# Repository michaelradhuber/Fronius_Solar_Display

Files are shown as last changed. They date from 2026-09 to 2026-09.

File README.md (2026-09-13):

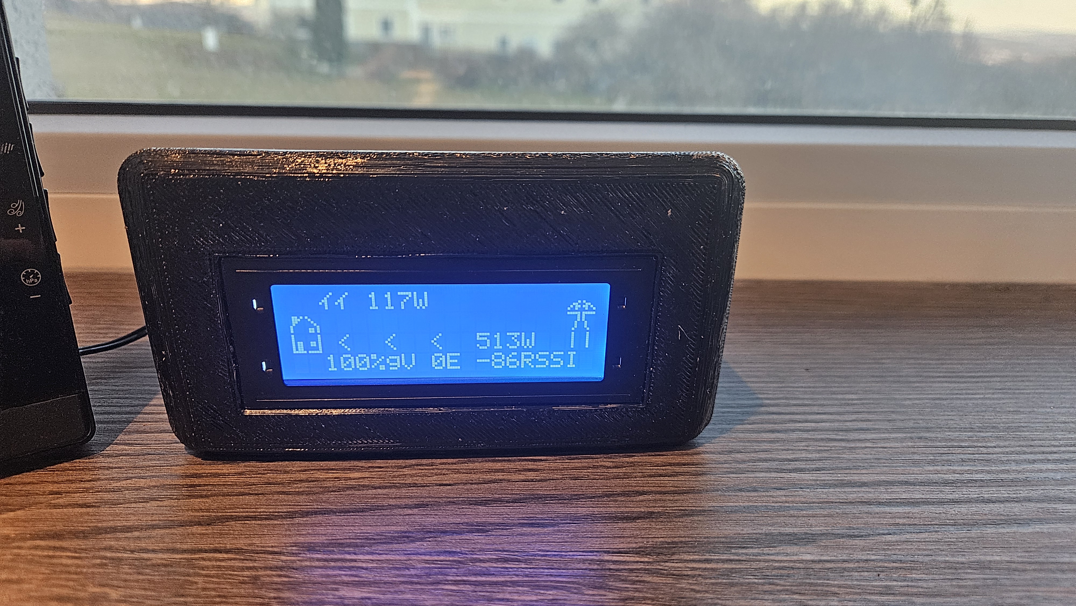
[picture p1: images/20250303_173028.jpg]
20x4 LCD solar display


# Fronius Solar Display

An ESP32 (Arduino) based solar power display that reads photovoltaic production, grid
import/export and home consumption from a Fronius inverter's **Solar API v1** and shows them
on a cheap 20×4 character LCD — no I²C backpack, no app, no website.

Put it somewhere you actually walk past: kitchen, hallway, living room. Its whole purpose is
a glance that tells you whether now is a good moment to run the dishwasher.

> **This is v2.** The v1 code is preserved on the [`v1` branch](../../tree/v1), along with
> its Fritzing sketch. The application logic is the same; v2 rewrites the hardware layer,
> fixes a set of latent memory bugs, adds OTA and makes the WiFi link actually survive a
> marginal signal. [ARCHITECTURE.md](ARCHITECTURE.md) documents all of it.

## System requirements

- A Fronius inverter with **Solar API v1** (Symo, Galvo, Gen24, Tauro …).
- A **Fronius Smart Meter** installed alongside your main electricity meter and connected to
  the inverter — without it there are no grid figures. Supplemental inverters not directly
  connected also work, provided they are registered via a Smart Meter.
- An IPv4 network, preferably a /24 (`255.255.255.0`) subnet.

## Features

- PV production, grid import/export and home consumption on a 20×4 LCD.
- Maximum grid-voltage deviation (`gV`). European grids run 230 V with a 10% (23 V) limit.
- WiFi signal strength (`RSSI`) and inverter connection errors (`E`), errors self-clearing
  after five minutes.
- Configured over WiFi through a captive portal ([WiFiManager](https://github.com/tzapu/WiFiManager)
  by @tzapu) — no credentials in the source.
- Remembers the inverter's IP **and MAC**, and re-finds it by MAC when DHCP moves it.
- **OTA updates** over WiFi once the first USB flash is done.
- Survives a weak link: radio tuning (power-save off, HT20, 802.11b retained), a blocking
  boot-connect retry loop, and active reconnect supervision rather than trusting the stack.

## Hardware

| | |
|---|---|
| **Board** | ESP32-WROOM-32 DevKit (4 MB flash) — v2 was developed on a uPesy board |
| **Display** | HD44780-compatible 20×4 character LCD, 4-bit parallel, run at **5 V** |
| **Contrast** | B10K potentiometer |
| **Power** | **An external 5 V supply — see below** |
| **Input** | The board's on-board BOOT button |

### Wiring

| LCD pin | Signal | ESP32 |
|---|---|---|
| 4 | RS | GPIO 13 |
| 6 | E | GPIO 33 |
| 11 | D4 | GPIO 14 |
| 12 | D5 | GPIO 27 |
| 13 | D6 | GPIO 26 |
| 14 | D7 | GPIO 25 |
| 1, 5, 16 | VSS, **RW**, backlight cathode | GND |
| 2, 15 | VDD, backlight anode | 5V |
| 3 | V0 | Potentiometer wiper (outer legs to 5 V and GND) |

Pins 7–10 (D0–D3) stay open — 4-bit mode uses D4–D7 only.

All eight connections land on the DevKit's **left header**, so no wire crosses the board:

```
3V3 EN 36 39 34 35 32  33  25  26  27  14  12  GND  13  9 10 11  5V
                        E  D7  D6  D5  D4  ✗  rail  RS  ·  ·  ·  rail
```

Three things that are not optional:

- **`RW` (pin 5) must be tied to GND.** It puts the HD44780 in write-only mode, which is also
  what makes driving a 5 V display from 3.3 V GPIOs safe — the data pins stay inputs and
  never drive 5 V back into a non-5 V-tolerant ESP32.
- **Leave GPIO 12 bare.** It is the MTDI strapping pin: held high at reset it selects 1.8 V
  for the flash core and the module will not boot. It sits *inside* the run of pins we use,
  between D4 and GND, so it is easy to hit by miscounting. (v1 ran EN here and got away with
  it; v2 uses GPIO 33 instead.)
- **Use an external 5 V supply.** USB power is not enough. The LCD with its backlight plus
  the ESP32's transmit bursts sag the rail, and because contrast is ratiometric the display
  goes unreadable — which looks exactly like a wiring fault. USB is for flashing and serial.

## Build & flash

[PlatformIO](https://platformio.org/). The first flash of a blank board must go over USB,
because OTA needs firmware that already contains ArduinoOTA.

```bash
# USB — the default environment
pio run -t upload
pio device monitor -b 115200

# Over the network, once it is on WiFi
pio run -e esp32-wroom-32-ota -t upload
```

If `esptool` reports `Wrong boot mode detected (0x13)`, this board's auto-reset isn't pulling
GPIO 0 low: **hold BOOT through the `Connecting......` dots** and release once writing starts.

> ⚠️ `OTA_PASSWORD` is `"changeme"` in [src/main.cpp](src/main.cpp). Anyone on your LAN can
> reach port 3232. Change it, and keep `upload_flags = --auth=…` in
> [platformio.ini](platformio.ini) matching.

## First run

1. Power up. The display shows a splash, then tries saved credentials.
2. With none saved it raises an access point, **`SOLAR_POWER_DISPLAY`**. Join it and open
   `192.168.4.1`.
3. Enter your WiFi details and the inverter's IPv4 address.
4. To wipe the configuration later, hold the **BOOT** button for three seconds.

## Case

[`case/`](case/) holds a 3D-printable cap for the 20×4 module, under its own licence.

## Documentation

[ARCHITECTURE.md](ARCHITECTURE.md) is the real reference: the runtime state machine, the WiFi
supervision logic and why it exists, the Solar API quirks, the memory bugs fixed in the port,
and a catalogue of the hardware traps this project has walked into — including the 0 Ω antenna
resistor that cost 30 dB, and the serial-terminal DTR line that silently factory-resets the
device.

## Licence

[Creative Commons Attribution-NonCommercial 4.0 International](LICENSE.md).

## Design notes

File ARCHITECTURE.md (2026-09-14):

# Fronius Solar Power Display — v2

A 20×4 character LCD that shows live PV production, grid import/export and grid-voltage
deviation, read from a Fronius inverter's **Solar API v1** over the local network.

v2 began as a port of the original `Fronius_Solar_Display` (ESP32 WROOM DA / DevKit V1) to
the **Waveshare ESP32-S3-ETH**. The application logic is the same; the board change forced a
new pinout, and a set of latent memory bugs were fixed along the way (see
[Bugs fixed in the port](#bugs-fixed-in-the-port)).

**That S3 board has since died and been replaced by a uPesy ESP-WROOM-32 DevKit** — back to
v1's board family, and with it v1's pinout (one wire excepted). Everything below describes
the WROOM-32; sections that only ever applied to the S3 are marked *retired*. All of the
v2 work above the hardware layer — the memory fixes, the WiFi supervision, the ARP scanner —
carried over untouched.

**Pre-port source (v1):** `X:\Code\PlatformIO\Projects\Fronius_Solar_Display` — a separate
git repo whose whole application lives in one file, `src/Display.cpp`. It is the reference
for anything in this document that says "v1 did X", and its `README.md` carries the wiring
table and Fritzing sketch the current pinout is derived from.

---

## Hardware

| | |
|---|---|
| **Board** | uPesy ESP-WROOM-32 DevKit (ESP32-D0WD, 4 MB flash, no PSRAM) |
| **Display** | HD44780-compatible 20×4 character LCD, 4-bit parallel mode, run at 5 V |
| **Contrast** | B10K potentiometer: outer legs to 5 V / GND, wiper to LCD pin 3 (V0) |
| **Network** | WiFi (STA) |
| **Input** | The on-board **BOOT** button (GPIO0) |

### Pinout

```
LCD (LiquidCrystal, 4-bit)      RS=13  EN=33  D4=14  D5=27  D6=26  D7=25
LCD power                       VDD + backlight anode -> 5V ; VSS + RW + cathode -> GND
Button                          GPIO0 (BOOT, INPUT_PULLUP, on-board — no wire)
```

All eight connections land on the **left header**, which runs top to bottom:

```
3V3 EN 36 39 34 35 32  33  25  26  27  14  12  GND  13  9 10 11  5V
                        E  D7  D6  D5  D4  ✗  rail  RS  ·  ·  ·  rail
```

So D7–D4 sit on four consecutive pads in descending order and no wire crosses the board.

**`RW` (LCD pin 5) must be tied to GND.** The 6-argument `LiquidCrystal` constructor never
drives RW, and grounding it pins the HD44780 in write-only mode — which is also what makes
the 3.3 V / 5 V mix safe. The LCD's data pins stay inputs and never drive 5 V back into a
non-5 V-tolerant GPIO. Leave RW floating and the display can drive the bus.

**Pins you must not use on this board:**

| GPIO | Why |
|---|---|
| **12** | **MTDI strapping pin — leave bare.** Sampled at reset to select the flash core voltage; held high it picks 1.8 V and the module will not boot or flash. v1 ran LCD EN here and survived (the HD44780's E input is high-impedance and never pulled it up), but the pad sits *inside* the run we use — between D4 and GND — so a miscount of one lands on it. EN was moved to 33. |
| **6–11** | SPI flash. Never usable. |
| **34–39** | Input only — cannot drive an LCD line. |
| **0, 2, 15** | Strapping. GPIO0 is the BOOT button (fine as an input); avoid the others for driven outputs. |
| **1, 3** | UART0 — the USB serial console. |

Free and safe for driven outputs: `4, 5, 13, 14, 16–19, 21–23, 25–27, 32, 33`.

### Power — the display needs an external 5 V supply

**USB power is not enough to run this build, and the way it fails looks like a wiring
fault.** Confirmed empirically during the WROOM-32 rewire: identical firmware, identical
soldering, blank or garbled LCD on USB, correct display the moment it ran from an external
5 V supply.

The load is the problem. A 20×4 module with its backlight is roughly 100–200 mA on its own,
and the ESP32 adds ~300 mA bursts every time the radio transmits. Between the host port's
current limit and the drop across the DevKit's protection diode, the 5 V rail sags under
those bursts. Two consequences, and neither announces itself:

- **Contrast is ratiometric.** V0 comes off a pot strung between 5 V and GND, so when VDD
  droops the contrast bias droops with it and the panel goes unreadable — looking exactly
  like a pot that needs adjusting.
- **A brownout mid-write desynchronises the 4-bit bus.** The HD44780 takes commands as two
  nibbles; interrupt it between them and every subsequent byte is shifted. The display then
  shows stable, confident garbage until it is power-cycled.

So: **USB for flashing and serial, external 5 V for running.** If the display misbehaves,
rule out the supply before touching the wiring.

> The same nibble-desync explains a symptom that is *not* a hardware fault: the HD44780 has
> no reset line, so it does not restart when the ESP32 does. `LiquidCrystal::begin()` assumes
> a controller that powered up in 8-bit mode, so re-running it against one already in 4-bit
> mode can leave the bus out of sync. After any reset loop, **power-cycle the LCD** before
> concluding anything about the wiring.

### The antenna switch (0 R resistor) — *retired with the S3 board*

Kept because the lesson generalises and [Radio tuning](#radio-tuning-tuneradio) refers back
to it. The WROOM-32 has a fixed module antenna and no such switch — one less
thing to get wrong.

**The S3 board shipped wired to its on-board PCB antenna, and plugging an antenna into the
IPEX connector did nothing until you moved a 0 Ω resistor.** From the
[Waveshare wiki](docs/ESP32-S3-ETH%20-%20Waveshare%20Wiki.pdf) FAQ, *"How to switch to the
external antenna for IPEX 1 generation"*:

> the default weld is a **vertical** 0R resistor. If you want to switch to an external antenna,
> you need to re-solder the 0R resistor to a **horizontal** position.

| Bridge | Selects |
|---|---|
| **Vertical** (factory default) | On-board PCB antenna |
| **Horizontal** | External antenna on the IPEX / u.FL connector |

This cost a lot of debugging time. The display sat at **-80 to -90 dBm from an AP 8 m away in
the same room, line of sight** — where free-space loss says it should read in the **-40s**. A
30-45 dB deficit is not distance, clutter or a bad router; it is a broken RF path. The
symptoms it produced looked exactly like flaky WiFi: dropped associations, inverter polls
timing out, and the AP periodically needing a restart before the display could rejoin (an
access point will give up on a station it can barely hear).

Two traps, both of which we walked into:

- **The naming is a coin-flip and the default is "internal".** Bridging *vertical* — the
  intuitive "I soldered the thing" move — selects the on-board antenna, i.e. the one you were
  trying to replace.
- **Soldering the antenna directly to the bridge pads "works", and is still wrong.** Any
  conductor on the RF feed radiates, so RSSI *improves* and the change looks correct. But the
  feed is a 50 Ω impedance-controlled node expecting exactly one load. Leave the vertical
  bridge in place and solder an antenna on top, and both radiators hang off it in parallel:
  the match is destroyed and much of the power reflects back into the radio. **Relative
  improvement proves the path was starved. It does not prove the new path is good** — only the
  absolute number does, and -85 dBm at 8 m is not good.

Correct configuration: horizontal bridge **only** (remove every trace of the vertical one),
antenna clicked onto the **u.FL connector**, never soldered to the pads.

### Ethernet — *retired with the S3 board*

The S3 board was an *ETH* variant with an on-board W5500; the firmware never used it, and
the `Ethernet_Generic` dependency and `W5500_SPI_*` build flags were removed during the v2
port (the library never read those macros, and two of the five pins were wrong anyway).
The WROOM-32 has no Ethernet at all, so this is now moot.

One landmine worth keeping if Ethernet ever comes back on any board: `Ethernet_Generic`'s
header is `Ethernet_Generic.h`, **not** `Ethernet.h`, and its `Dns_Impl.h` does
`#define DNS_PORT 53`, which macro-clobbers WiFiManager's `const byte DNS_PORT` unless
`WiFiManager.h` is included first.

---

## Layout

```
src/main.cpp                      everything: state machine, Fronius client, LCD, OTA
src/LiquidCrystal-master/         vendored HD44780 driver
lib/netscanner-lib/               ARP-table scanner (find a host by IP or by MAC)
platformio.ini                    two envs: USB flash + OTA flash
```

## Build & flash

```bash
# USB is the default env — this is the normal way to flash
pio run -t upload
pio device monitor -b 115200

# Opt in to a network flash (board must already be running OTA firmware)
pio run -e esp32-wroom-32-ota -t upload
```

`default_envs` pins the default to the USB env: a bare `pio run -t upload` will **not**
try to flash over OTA. Without that, PlatformIO runs every env and the OTA upload fails
with `Host solar-display.local Not Found`.

**The partition table is not the default, and must not go back to it.** `min_spiffs.csv`
gives each OTA slot 1'966'080 B. The stock 4 MB layout gives 1'310'720 B, and this firmware
is ~1'238'000 B — 94% full, with the overflow surfacing as a linker error that reads like a
code problem. Nothing here uses SPIFFS/LittleFS, so the smaller data partition costs nothing.

**COM port.** Unlike the S3's native USB, the DevKit's CP2102/CH340 bridge keeps a stable
COM number across resets, so pinning `upload_port` is safe — it is just unnecessary, and
`upload_port` is left unset so PlatformIO auto-detects. This board currently comes up on
**COM5**.

Unlike the S3, this board needs a **USB-serial driver** (CP210x or CH340, depending on which
bridge the board carries) — it does not enumerate as inbox USB CDC.

**Auto-reset into download mode does not work on this board.** `esptool` pulses DTR/RTS to
drive EN and GPIO0 through the usual two-transistor circuit; here the EN half works and the
GPIO0 half does not, so the chip resets and boots normally instead:

```
A fatal error occurred: Failed to connect to ESP32: Wrong boot mode detected (0x13)!
```

`0x13` is `SPI_FAST_FLASH_BOOT` — a normal boot, i.e. GPIO0 was never pulled low. **Hold the
BOOT button down through the `Connecting......` dots** and release it once writing starts.
Setting download mode by hand beforehand does *not* help on its own: esptool's own reset
pulse knocks the chip straight back out of it before the sync.

### Do not let a serial terminal assert DTR

**On this board, opening the serial port with DTR asserted factory-resets the device.**

DTR drives GPIO0 through the auto-reset circuit, so asserting it holds GPIO0 low.
`checkButton()` reads that as the BOOT button, and after `LOW` for three seconds it calls
`wm.resetSettings()` and `preferences.clear()` and reboots — wiping the WiFi credentials and
the inverter IP/MAC. With DTR held, this repeats every ~8 s:

```
WIFI: Button Pressed
WIFI: Button Held - erasing config, restarting
*wm:SETTINGS ERASED
rst:0xc (SW_CPU_RESET)
```

This bit us during the rewire and, because it also reset the ESP32 without resetting the
LCD, it produced garbled output that read convincingly as a soldering fault.

| Lines | Effect |
|---|---|
| DTR high, RTS low | GPIO0 **low** — the config-wipe trap |
| DTR low, RTS high | EN low — clean reset, GPIO0 stays high |
| Both low (or both high) | Idle — safe for passive monitoring |

`pio device monitor` is safe. Raw `System.IO.Ports.SerialPort` is **not**: it defaults to
`DtrEnable = false`, but any code that sets it true will wipe the device. To reset the board
cleanly from a terminal, pulse RTS alone.

This is worth guarding in firmware — ignore `TRIGGER_PIN` for the first few seconds after
boot, or trigger on a press edge rather than a level — but it is not fixed yet.

> The S3-era advice "if the board does not enumerate, suspect the LCD pinout" no longer
> applies — that was specific to GPIO 19/20 being the S3's native USB lines. On the
> WROOM-32 the USB bridge is independent of every pin the LCD touches.

### Building from the `X:` share

This tree lives on a VPN-mounted SMB share, and that breaks two things.

**SCons cannot write its signature database over SMB.** A build dies at the end with
`OSError: [Errno 22] Invalid argument: ...\.pio\build\...\.sconsign311.tmp`, *after* the
compile has already succeeded — so it looks like a code failure but isn't. Put the build
directory on a local disk:

```bash
PLATFORMIO_BUILD_DIR=C:/pio-build/fronius-display-v2 pio run
```

**The VPN and the display are mutually exclusive.** `X:` *is* the VPN, but the display is
on the local LAN and OTA can't reach it while the VPN is up. So the order is: build with the
VPN up (source must be reachable), drop the VPN, then flash. Once the VPN is down the source
tree is gone, so PlatformIO can't run — push the already-built binary with `espota.py`
directly, which needs no project directory:

```bash
python "$HOME/.platformio/packages/framework-arduinoespressif32/tools/espota.py" \
  -i solar-display.local -p 3232 -a changeme \
  -f C:/pio-build/fronius-display-v2/esp32-wroom-32/firmware.bin -r -d
```

---

## Runtime state machine

`loop()` is a cascade of guards. Each stage runs only once the previous one is satisfied,
and most stages `return` so a single iteration does one thing.

```
                    ┌──────────────┐
  boot ───────────► │ splash (LCD) │
                    └──────┬───────┘
                           ▼
              boot connect loop (blocking)  2 × 10 s on saved creds; see below
                           ▼
                  wm.autoConnect()          already connected → returns true
                           │
              ┌────────────┴────────────┐
         connected                  not connected
              │                          │
              │                          ▼
              │                 ┌──────────────────┐
              │                 │ CONFIG PORTAL    │  AP: SOLAR_POWER_DISPLAY
              │                 │ (WiFiManager)    │  user enters WiFi + inverter IP
              │                 └────────┬─────────┘
              ▼                          │
       ┌─────────────┐ ◄─────────────────┘
       │ OTA::begin  │  (lazy: also fires if WiFi arrives later)
       └──────┬──────┘
              ▼
        manageWiFi()  ◄─── every loop; see WiFi supervision below
              │
       WL_CONNECTED? ── no ──► reconnect / AP portal, and do nothing else
              │ yes
              ▼
      inverterIPSet?  ── no ──► web portal; "Set inverter IP" held on the LCD, wait
              │ yes
              ▼
      inverterMACSet? ── no ──► resolveMAC()      ARP, non-blocking, retry 1s ×15 → 30s
              │ yes
              ▼
      initSuccess?    ── no ──► runInverterHandshake()      one attempt per call
              │ yes                 ├─ ARP IP_char (5 tries): still our MAC?
              │                     │    └─ no → MAC sweep (≤ every 30 min) → found? save IP
              │                     ├─ GET /solar_api/GetAPIVersion.cgi → must be 1
              │                     └─ any failure → "Inverter unavailable" on the LCD,
              │                          retry after 30 s, doubling to 5 min.
              │                          Never deletes the stored IP/MAC, never reboots.
              ▼
    ┌────────────────────────┐
    │ POLL every 5s          │  getInverterData()  + getGridVoltage()
    │  → drawPowerScreen()   │  >5 errors → back to handshake retries (no reboot)
    └────────────────────────┘  errors forgotten after 5 min
```

### Boot connect loop (before WiFiManager runs)

`wm.autoConnect()` cannot be trusted to actually *try*. It makes exactly **one** attempt
with **no timeout and no retries** (`_connectTimeout = 0`, `_connectRetries = 1`), and the
Arduino 3.x core fails that attempt in ~0 ms on any transient bring-up hiccup —
`enableSTA()` failing, `ESP_NETIF_STARTED_BIT` not arriving within 1 s, or
`esp_wifi_connect()` erroring. All of those are `log_e()` only, invisible at the default
`CORE_DEBUG_LEVEL=0`. The observed symptom: the device jumps into the AP portal
*immediately* after reset, with none of the usual 3–5 s connect lag, even though the router
is up and the credentials are good.

So `setup()` now does it the old, classic way first: if credentials are saved, a blocking
`WiFi.begin()` + wait loop, retried (`WIFI_BOOT_ATTEMPTS` × `WIFI_BOOT_ATTEMPT_MS`,
2 × 10 s), with the attempt counter on the LCD. **No other code runs until this window has
passed.** Re-issuing `begin()` re-runs the whole STA bring-up, which is precisely the part
that fails on the bad boots. Only after every attempt has failed is `wm.autoConnect()`
allowed to fall through to the AP portal; when the loop has already connected,
`autoConnect()` sees `WL_CONNECTED` and returns true without touching anything.

### WiFi supervision (`manageWiFi()`)

**Nothing else re-establishes the station link.** Not WiFiManager: its ESP32 disconnect
handler only calls `WiFi.reconnect()` under `#ifdef esp32autoreconnect`, which is not
defined. And not the Arduino core's silent auto-reconnect, because of this, in
`WiFiManager::startConfigPortal()`:

```cpp
if(_disableSTA || (!WiFi.isConnected() && _disableSTAConn)){   // _disableSTAConn defaults true
  WiFi_Disconnect();
  WiFi_enableSTA(false);            // <-- the station interface is switched OFF
}
```

Raising the soft-AP portal turns the station **off**. A device parked in that portal cannot
see the router come back — there is nothing left to see it with. Neither v1 nor early v2 had
any code to get out again, so a router outage was a one-way trip: poll errors → reboot →
`autoConnect()` fails while the router is still down → AP portal → stranded until someone
power-cycled it.

`manageWiFi()` runs once per `loop()` and owns every transition:

| State | Action |
|---|---|
| **Rising edge** (link came back) | Tear down the AP portal, clear `connectErrors`, start OTA if it was never started, repaint the LCD, force an immediate poll |
| **Falling edge** (link dropped) | Note the time, tell the user, stop polling |
| **Offline, no portal** | `WiFi.begin()` (saved NVS creds) every **20 s** |
| **Offline > 2 min** | Raise the AP portal so the user *can* re-provision — without giving up on the saved network |
| **AP portal idle > 15 min** | Take it down, switch the station back on, retry the saved credentials. If the router is still gone, the 2-minute timer raises the AP again. The station is off while the AP is up, so a router that returns mid-portal is only noticed once the 15 minutes run out |
| **AP portal, client connected** | Leave it up. `WiFi.softAPgetStationNum() > 0` keeps pushing the deadline out, so it never dies under someone who is mid-configuration |
| **AP portal, no saved SSID** | Leave it up forever. A fresh device has nothing to fall back to |

So the device alternates AP ⇄ STA instead of committing to either, and always finds the
router again on its own.

Two supporting changes make this work:

- **`wm.setConfigPortalTimeout(0)`.** WiFiManager's own portal timeout would shut the AP down
  and leave the device with *neither* a portal nor a station link — LCD frozen on the "join
  AP" screen, permanently. Portal lifetime is `manageWiFi()`'s job now.
- **The poll loop returns early unless `WL_CONNECTED`.** Without that guard a WiFi outage
  looked exactly like a dead inverter: the 5-second poll kept firing, every HTTP GET failed,
  and six failures rebooted the box straight into the AP portal. The inverter is not at fault
  for the router being down, and `connectErrors` no longer says it is.

### Radio tuning (`tuneRadio()`)

Written while the display was reading **-80 to -90 dBm** and the link was dropping constantly.
That turned out to be a hardware fault, not a site problem — see
[The antenna switch](#the-antenna-switch-0-r-resistor--retired-with-the-s3-board). Do not read this section as evidence
that the installation is inherently marginal; **8 m of clear line-of-sight should read in the
-40s**, and if it doesn't, fix the antenna before touching anything here.

The tuning is still worth having — it is what you want on any WiFi link you cannot make short
— but it buys single-digit dB. It cannot rescue a broken RF path, and it was never the reason
the display kept falling off the network.

`tuneRadio()` trades away everything we don't need for link margin:

| Setting | Why |
|---|---|
| `WiFi.setSleep(false)` | **The important one.** The default `WIFI_PS_MIN_MODEM` parks the radio between beacons. At -85 dBm missed beacons are common, and a run of them drops the association. The display is mains-powered — there is nothing to save |
| `setTxPower(WIFI_POWER_19_5dBm)` | Full TX. See the caveat below |
| `esp_wifi_set_bandwidth(HT20)` | A 40 MHz channel spreads the same power over twice the bandwidth: ~3 dB of receive sensitivity traded for throughput we have no use for (the payload is a few kB every 5 s) |
| `esp_wifi_set_protocol(11B\|11G\|11N)` | Keep 802.11b. Dropping it as "legacy" is the obvious move and it is wrong: the b rates go down to 1 Mbps and have the best receiver sensitivity in the set — they are the rates that still carry a frame at -90 dBm |
| `setSortMethod(WIFI_CONNECT_AP_BY_SIGNAL)` | If the SSID is served by more than one radio, take the loudest rather than the first one found |

> ⚠️ **TX power cannot improve the RSSI on the LCD.** That number is how well the *display
> hears the router*; TX power governs how well the *router hears the display*. No transmitter
> can talk itself louder into its own receiver. Expect the on-screen figure not to move — what
> should improve is the AP no longer losing us mid-conversation.

**`tuneRadio()` is re-applied on every reconnect, not just at boot.** A `WIFI_STA` →
`WIFI_AP` mode change — precisely what a trip through the config portal is — resets
power-save, bandwidth and TX power to the IDF defaults. Setting them once in `setup()` would
silently lose them the first time the display fell back to the AP, i.e. exactly when they
matter most.

### Persisted state (`Preferences`, namespace `inverter_config`)

| Key | Type | Meaning |
|---|---|---|
| `inverter_IP` | string | Inverter's IPv4, entered by the user in the portal |
| `inverter_MAC` | string | Resolved via ARP. The **stable identity** — IPs move, MACs don't |
| `inverterIPSet` | bool | Set by the user in the portal. **Never cleared by a failed lookup** — see below |
| `inverterMACSet` | bool | Gate for `resolveMAC()` |

WiFi credentials are stored separately by WiFiManager.

### Why the MAC matters

The inverter is found by **IP**, but identified by **MAC**. `runInverterHandshake()` ARPs
`inverter_IP` — up to five requests, 500 ms apart — and compares the answer to the stored MAC:

- **Match** → check the API version, start polling.
- **No answer, or a different MAC** → the lease may have moved. `netscanner.findIPbyMAC()`
  sweeps the /24; if the MAC turns up at a new address, that IP is saved and the handshake
  carries on without a reboot.
- **Still not found** → the inverter is *unavailable*, not *misconfigured*. The LCD says so,
  and the handshake retries after 30 s, doubling to 5 min.

This is what makes the display survive a DHCP reshuffle without the user touching it.
The sweep is slow (254 addresses × 500 ms ≈ **2 minutes**, blocking `loop()`), so it runs at
most every 30 minutes; the cheap single-IP check runs on every retry.

### The inverter disappears every night — never delete its address

**Nothing in the handshake or the poll loop deletes `inverter_IP` / `inverter_MAC`, or
reboots, because the inverter did not answer.** Only the user changes the address, in the
portal.

Until September 2026 both happened, and together they stranded the display:

1. The inverter stops answering. Fronius Datamanagers switch off at night unless **Night
   Mode** is enabled; a single lost ARP reply at a weak RSSI has the same effect.
2. More than five failed polls → `ESP.restart()`.
3. The boot handshake runs while the inverter is still silent: no ARP answer, MAC not found
   by the sweep → `inverterIPSet = false` written to NVS → reboot.
4. From then on `loop()` has no IP and does nothing. Its only prompt, "Set inverter IP", was
   painted once, when the web portal opened; the next WiFi reconnect painted
   `WIFI: connected / <ip>` over it, and that stayed on screen until someone re-entered the IP.

It looked exactly like a firmware hang, and wasn't one. v1 had the same intent but a broken
wipe (`putString("inverter_IP", 0)`); the v2 port fixed the wipe and so made it *work*.

Now: failed handshakes keep the stored address and retry with backoff; failed polls drop back
to the handshake instead of rebooting; and `loop()` re-claims the LCD for the two screens that
describe a waiting state ("Set inverter IP", "Inverter unavailable") whenever something else
has painted over them.

Closed on the way: the handshake read an unreachable API as `APIVersion 0` — `httpGETRequest()`
returns `"{}"` on failure, which parses cleanly — and rebooted with "API version not supported".

---

## Fronius Solar API

Base: `http://<inverter_ip>`

Reference documents, both in [docs/](docs/):

- [solar_api.pdf](docs/solar_api.pdf) — Fronius Solar API v1 specification. Section **4.8**
  covers `GetMeterRealtimeData`; **4.8.5** defines the channels used here.
- [solarApiv1.json](docs/solarApiv1.json) — JSON schema for the same responses.

| Endpoint | Used for |
|---|---|
| `/solar_api/GetAPIVersion.cgi` | Handshake. `APIVersion` must be `1`; anything else — including no reply — shows "Inverter unavailable" and retries. |
| `/solar_api/v1/GetPowerFlowRealtimeData.fcgi` | PV production, grid flow |
| `/solar_api/v1/GetMeterRealtimeData.cgi?Scope=System` | Per-phase grid voltage |

**PV production** sums `Body.Data.Inverters[1..9].P`, and — when `inverterAsSmartMeter` is
true — also adds `SecondaryMeters[1..9].P` for meters whose `Category` is
`METER_CAT_WR`, `METER_CAT_BAT`, or `METER_CAT_PV_BAT` (battery / secondary PV).

**Grid flow** is `Body.Data.Site.P_Grid`:

- `P_Grid > 0` → **importing** from the grid. Rendered `<  <  <  1.2kW`.
- `P_Grid ≤ 0` → **exporting**. Rendered `1.2kW  >  >  >`.

**Home consumption** = PV + grid. (Computed, but not currently shown.)

**Voltage deviation** takes the phase furthest from nominal 230 V and reports it as a
percentage — `100%` is nominal, `106%` means a phase is sitting ~244 V.

The meter to read it from is **not** at a fixed key. `Body.Data` is an object keyed by meter
*device ID*, and those IDs are assigned by the Datamanager: this system, with a grid meter
and a second one on the Carport, reports them as `"2"` and `"3"` — there is no `"0"` at all.
Both v1 and early v2 hardcoded `Body.Data.0`, so the lookup silently missed and the display
sat at `0%gV` forever.

`getGridVoltage()` now selects by `Meter_Location_Current` (spec 4.8.5):

| Value | Meaning | Used? |
|---|---|---|
| `0` | Grid interconnection point (primary meter) | **Yes — this is the one we want** |
| `1` | Load path (primary meter) | Fallback only |
| `3` | External generator (secondary, e.g. the Carport meter) | Never |
| `256`–`511` | Subloads (secondary) | Never |

A secondary meter reports the voltage at *its own* connection point, not at the grid feed­-in
point, so it must never be picked for gV.

## The display

```
  ┌────────────────────┐
  │  ☼☼ 4.2kW        /\│   row 0: PV production, pole top
  │/\                | |│   row 1: house roof, pole
  │|_|  <  <  <  820W| |│   row 2: house base, grid flow + arrows
  │  101%gV 0E -54dRSSI │   row 3: voltage deviation, error count, WiFi RSSI
  └────────────────────┘
```

The HD44780 has **8 CGRAM slots**. Slots 0–3 hold the house (set once in `setup()`);
slots 4–7 hold the power pole (re-uploaded on each redraw in `drawPowerScreen()`).

---

## OTA

`ArduinoOTA` on the default port 3232, advertised over mDNS as `solar-display.local`.

- Configured in `setupOTA()`, lazily — it starts whenever WiFi first connects, whether at
  boot or later via the portal.
- `initSuccess` is cleared on OTA start so the 5-second poll loop stops writing to the LCD
  mid-flash.
- Progress is drawn as a percentage plus a 20-cell bar on the bottom row.

> ⚠️ **`OTA_PASSWORD` is `"changeme"`.** Anyone on the LAN can reach port 3232. Change it in
> [src/main.cpp](src/main.cpp), and keep `upload_flags = --auth=...` in
> [platformio.ini](platformio.ini) in sync.

---

## Bugs fixed in the port

v1's shipped firmware had three memory bugs. They are fixed here; if you ever go back to
the v1 tree, they are still there.

| Bug | Detail |
|---|---|
| **Stack overflow on every redraw** | The grid-flow string was built with `strcat()` into `char buffer[7]` / `char gridArrows[12]`. The export branch appended 8 bytes to an already-full 7-byte buffer — ~15 bytes into 7. It fired *whenever the system was exporting*, i.e. most of a sunny day. Now one `snprintf` into a correctly-sized buffer. |
| **URL buffer overflow** | `char serverPathData[64]` for `"http://"` (7) + IP (≤15) + endpoint (43) + NUL = **66**. Now `URL_LEN = 96` with a checked `snprintf`. |
| **`putString(key, 0)`** | The literal `0` binds to `const char*` → **nullptr**. Three call sites. Replaced with clearing the corresponding bool flag. |
| **Infinite loops in netscanner** | `for (char i = 1; i < 255; i++)` — a signed `char` overflows at 127 and never reaches 255. Three occurrences. Now `int`. |
| **`splitIp()` self-destruction** | It ran `strtok()` directly on `interface_ip`, overwriting the `.` separators with NULs, so the member was destroyed by the first call. Now works on a copy via `strtok_r`. |
| **Null-deref in `resolveMAC()`** | `etharp_find_addr()` returns nothing on the first call (ARP is async), and v1 dereferenced the null result. v1 papered over it with `delay(100)`; v2 returns early and retries on a timer (1 s × 15, then 30 s). |
| **`tcpip_adapter` removed in IDF 5** | netscanner used `tcpip_adapter_get_ip_info()` / `TCPIP_ADAPTER_IF_STA`, gone since ESP-IDF 5. Replaced with `WiFi.localIP()` and `netif_default`. |

### Also changed

- **`.ino` → `.cpp`**: the Arduino IDE auto-generates function prototypes; PlatformIO does
  not. Explicit forward declarations are now required and present.
- **`autoConnect()` instead of unconditional `startConfigPortal()`** — v1 forced the portal
  open on every boot and never tried saved credentials.
- **Portal restart loop** — v1's `loop()` called `startConfigPortal()` on *every iteration*
  while the IP was unset, continuously restarting it. Now guarded by `portalRunning`.
- **Wrong callback** — v1 wired `setSaveConfigCallback(saveParamCallback)`, so saving *WiFi
  credentials* set `inverterIPSet = true` even if no inverter IP was ever entered. Only
  `setSaveParamsCallback` is wired now.
- **IP validation** (`isValidIP`) before persisting; garbage no longer gets saved and fed to ARP.
- **MAC parameter field** was 15 chars for a 17-char MAC — it truncated. Now 18.
- `strcpy` → `strlcpy` throughout; `connectErrors` now resets on a successful poll.

---

## Known gaps

- `homeConsumption` is computed but never displayed.
- The netscanner MAC sweep blocks for ~2 minutes; it only runs on the recovery path, but it
  does freeze the UI while it runs.
- No TLS — the Solar API is plain HTTP on the LAN.
- `DEVICE_ID` is a compile-time constant shared by every unit built from this tree.

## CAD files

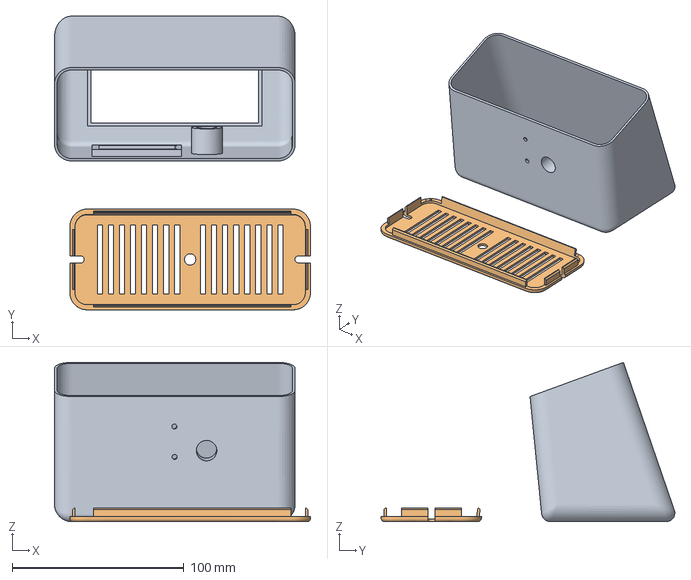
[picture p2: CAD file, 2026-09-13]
case/20x4_cap_all.3mf
148.9 x 170.8 x 92.6 mm
20x4_case
20x4_cap

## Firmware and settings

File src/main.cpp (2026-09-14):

// Fronius Solar Power Display - v2
// Ported from Fronius_Solar_Display (ESP32 WROOM DA) to the Waveshare ESP32-S3-ETH.
// Network scanner: https://github.com/agentzex/ESP_network_ip_scanner

#include <Arduino.h>

// WiFi & Network
#include <WiFi.h>
#include <WiFiManager.h>
#include <Preferences.h>
#include <esp_wifi.h>     // ps / bandwidth / protocol / tx-power knobs Arduino doesn't expose
#include <lwip/etharp.h>
#include <lwip/ip4_addr.h>
#include <lwip/tcpip.h>   // LOCK_TCPIP_CORE / UNLOCK_TCPIP_CORE
#include <netscanner.h>

// JSON, HTTP GET
#include <ArduinoJson.h>
#include <HTTPClient.h>

// Over-the-air firmware update
#include <ArduinoOTA.h>

// Local Library (Ensure folder structure is src/LiquidCrystal-master/src/)
#include "LiquidCrystal-master/src/LiquidCrystal.h"

/* ---- DEBUG SECTION ---- */
#define DEBUG //Comment out for production use
#ifdef DEBUG
#define DEBUG_PRINT(x)       Serial.print(x)
#define DEBUG_PRINTLN(x)     Serial.println(x)
#define DEBUG_PRINTF(...)    Serial.printf(__VA_ARGS__)
#else
#define DEBUG_PRINT(x)
#define DEBUG_PRINTLN(x)
#define DEBUG_PRINTF(...)
#endif
/* ---- END DEBUG SECTION ---- */

#define TRIGGER_PIN 0   // BOOT button, on-board (same GPIO on the S3 and the WROOM-32)

const char DEVICE_VERSION[]   = "1A";
const char SOFTWARE_VERSION[] = "002_ALPHA";
const char DEVICE_ID[]        = "4280d4f3-204c-4bd8";
const char DEVICE_NAME[]      = "SOLAR POWER DISPLAY";
const char WIFI_APN[]         = "SOLAR_POWER_DISPLAY";

// OTA. The hostname is what appears in PlatformIO's `--upload-port` / mDNS.
// OTA_PASSWORD gates who may flash the device: anyone on the LAN can reach
// port 3232, so leaving this empty means anyone on your network can overwrite
// the firmware. Change it.
const char OTA_HOSTNAME[] = "solar-display";
const char OTA_PASSWORD[] = "changeme";

// Fronius Solar API v1 endpoints
const char HTTPSTRING[]      = "http://";
const char APIDATA[]         = "/solar_api/GetAPIVersion.cgi";
const char INVERTERDATA[]    = "/solar_api/v1/GetPowerFlowRealtimeData.fcgi";
const char INVERTERVOLTAGE[] = "/solar_api/v1/GetMeterRealtimeData.cgi?Scope=System";

// "xxx.xxx.xxx.xxx" = 15 chars + NUL
static const size_t IP_LEN  = 16;
// "xx:xx:xx:xx:xx:xx" = 17 chars + NUL
static const size_t MAC_LEN = 18;
// Longest URL is HTTPSTRING + a full IP + INVERTERVOLTAGE. v1 sized this by eye and
// overflowed: 7 + 15 + 43 + NUL = 66 did not fit its char[64].
static const size_t URL_LEN = 96;

static const uint32_t POLL_INTERVAL_MS  = 5000;
static const uint32_t ERROR_RESET_MS    = 300000;  // forget errors after 5 min
static const int      MAX_CONNECT_ERRORS = 5;      // reboot past this

// ARP is asynchronous: etharp_request() only queues the request, so the first
// etharp_find_addr() after it almost always misses. Poll on a timer rather than
// blocking with delay() the way v1 did.
static const uint32_t ARP_RETRY_FAST_MS = 1000;
static const uint32_t ARP_RETRY_SLOW_MS = 30000;
static const uint8_t  ARP_FAST_ATTEMPTS = 15;

// WiFi supervision. Nothing else re-establishes the STA link: WiFiManager's ESP32
// disconnect handler only reconnects under #ifdef esp32autoreconnect (not defined),
// and startConfigPortal() actively turns the station interface OFF. So we drive it.
static const uint32_t WIFI_RETRY_MS     = 20000;   // between reconnect attempts
static const uint32_t WIFI_GRACE_MS     = 120000;  // offline this long -> raise the AP
// 15 min: long enough to walk over with a phone and reconfigure. AP mode switches the
// station off, so the router is not retried at all while the portal is up.
static const uint32_t AP_PORTAL_MAX_MS  = 900000;  // ...then drop it and retry the STA

// Boot connect: classic blocking begin-and-wait, retried, BEFORE WiFiManager runs.
// wm.autoConnect() makes exactly one attempt with no timeout and no retries
// (_connectTimeout=0, _connectRetries=1): a transient radio/netif bring-up failure
// fails in ~0 ms - silently, the core only log_e()s it - and drops the device
// straight into the AP portal without ever having tried the router.
static const uint8_t  WIFI_BOOT_ATTEMPTS   = 2;      // 2 x 10 s = max 20 s before letting go
static const uint32_t WIFI_BOOT_ATTEMPT_MS = 10000;  // per-attempt connect window

// Inverter handshake retries. The inverter going quiet is normal - Fronius Datamanagers
// switch off at night unless Night Mode is enabled - so a failed handshake is retried
// with backoff. It never deletes the stored IP/MAC and never reboots: together those
// turned one night of a sleeping inverter into a device waiting for the user forever.
static const uint32_t HANDSHAKE_RETRY_MIN_MS = 30000;    // first retry after 30 s...
static const uint32_t HANDSHAKE_RETRY_MAX_MS = 300000;   // ...doubling up to 5 min
// Re-finding the inverter by MAC ARPs the whole /24 and blocks loop() for ~2 min
// (254 requests x 0.5 s), so it is rationed. The cheap single-IP check runs every retry.
static const uint32_t MAC_SWEEP_INTERVAL_MS  = 1800000;  // at most every 30 min

char IP_char[IP_LEN]   = "";
char MAC_char[MAC_LEN] = "";

struct PowerData {
  int pvProduction;
  int gridConsumption;
  int homeConsumption;
};

struct GridVoltage {
  float L1;
  float L2;
  float L3;
  int   devPercent;
};

int  connectErrors        = 0;
bool wm_nonblocking       = true;
bool inverterIPSet        = false;
bool inverterMACSet       = false;
bool inverterAsSmartMeter = true;
bool initSuccess          = false;
bool otaReady             = false;
uint32_t pollTimeout      = 0;
uint32_t errorTimeout     = 0;

bool     wifiOnline       = false;  // last observed link state, for edge detection
bool     haveSavedWiFi    = false;  // are there credentials to fall back on?
uint32_t offlineSince     = 0;      // millis() of the drop, 0 while online
uint32_t lastWifiRetry    = 0;
uint32_t apPortalStarted  = 0;      // millis() the soft-AP portal was raised

uint32_t lastHandshakeAttempt = 0;   // millis() of the last try, 0 = none pending
uint32_t handshakeBackoff     = HANDSHAKE_RETRY_MIN_MS;
uint32_t lastMacSweep         = 0;   // millis() of the last /24 sweep, 0 = none yet
const char *inverterProblem   = "";  // why the handshake failed, shown on the LCD

// Screens that must stay up until the state behind them changes. Every other paint
// (lcdMessage, the power screen, an HTTP error) marks the LCD Other, and loop()
// repaints the one that belongs there. Without this a WiFi reconnect message covered
// "Set inverter IP" and stayed on screen indefinitely.
enum class LcdScreen : uint8_t { Other, IpPrompt, InverterOffline };
LcdScreen onScreen = LcdScreen::Other;

WiFiManager wm;
WiFiManagerParameter inverter_input;
WiFiManagerParameter inverter_input_2;
WiFiManagerParameter inverter_text;
Preferences preferences;
NetScanner scanner;

// LCD Wiring: RS, EN, D4, D5, D6, D7
// Pinout for the uPesy ESP-WROOM-32 DevKit. All six land on the left header, which
// runs 33, 25, 26, 27, 14, 12, GND, 13 - so D7..D4 sit on four consecutive pads in
// descending order and nothing has to cross the board.
//
// EN is on 33, NOT on 12 the way v1 had it. GPIO12 is MTDI: the ESP32 samples it at
// reset to pick the flash core voltage, and held high it selects 1.8 V and the module
// will not boot or flash. v1 survived because the HD44780's E input is high-impedance
// and never pulled it up, but the pad sits in the middle of the run we are using, so
// leave it bare.
LiquidCrystal lcd(13, 33, 14, 27, 26, 25);

/* ---- Custom LCD glyphs ---- */
// The HD44780 has 8 CGRAM slots (0-7). Slots 0-3 hold the house and are set once
// in setup(); slots 4-7 hold the power pole.
byte bottomLeft[8]  = {0b10000, 0b10000, 0b10000, 0b10110, 0b10110, 0b10110, 0b10110, 0b11111};
byte bottomRight[8] = {0b00001, 0b00001, 0b00001, 0b01101, 0b01101, 0b00001, 0b00001, 0b11111};
byte topLeft[8]     = {0b00000, 0b01101, 0b01110, 0b01100, 0b01000, 0b10000, 0b10000, 0b10000};
byte topRight[8]    = {0b00000, 0b10000, 0b01000, 0b00100, 0b00010, 0b00001, 0b01101, 0b01101};

byte PoleTLeft[8]   = {0b00000, 0b00000, 0b00000, 0b00000, 0b00001, 0b00110, 0b01011, 0b10010};
byte PoleTRight[8]  = {0b00000, 0b00000, 0b00000, 0b00000, 0b10000, 0b01100, 0b11010, 0b01001};
byte PoleMLeft[8]   = {0b11111, 0b00001, 0b00001, 0b00001, 0b00010, 0b00010, 0b00010, 0b00100};
byte PoleMRight[8]  = {0b11111, 0b10000, 0b10000, 0b10000, 0b01000, 0b01000, 0b01000, 0b00100};

// Forward declarations. The Arduino IDE generates these automatically for .ino
// sketches; PlatformIO compiles this as a plain .cpp, so they must be explicit.
void checkButton();
void saveParamCallback();
void resolveMAC();
bool portalActive();
void openPortal();
void openAPPortal();
void manageWiFi();
void tuneRadio();
void setupOTA();
void runInverterHandshake();
void drawPowerScreen(const PowerData &prm, const GridVoltage &gv);
bool isValidIP(const char *s);
bool buildURL(char *out, size_t outLen, const char *endpoint);
eth_addr *get_sta_mac(const ip4_addr_t &ip);
String httpGETRequest(const char *serverPath);
PowerData getInverterData();
GridVoltage getGridVoltage();
void lcdMessage(const char *l0, const char *l1 = nullptr,
                const char *l2 = nullptr, const char *l3 = nullptr);
void showIPPrompt();
void showInverterOffline();

void setup() {
#ifdef DEBUG
  Serial.begin(115200);
#endif

  delay(2000);
  lcd.begin(20, 4);
  delay(100);
  lcd.clear();
  delay(100);

  lcd.createChar(0, bottomLeft);
  lcd.createChar(1, bottomRight);
  lcd.createChar(2, topLeft);
  lcd.createChar(3, topRight);
  delay(500);

  lcd.setCursor(0, 0);
  lcd.print(DEVICE_NAME);
  lcd.setCursor(0, 1);
  lcd.print(F("VERSION: "));  lcd.print(DEVICE_VERSION);
  lcd.setCursor(0, 2);
  lcd.print(F("SOFTWARE: ")); lcd.print(SOFTWARE_VERSION);
  lcd.setCursor(0, 3);
  lcd.print(DEVICE_ID);

  WiFi.mode(WIFI_STA);
  delay(100);
  tuneRadio();

  // The SSID is served by FOUR routers in and around the house, so always take the
  // loudest. Two places must agree on that:
  //
  // 1) These setters - but they only apply to connects that pass an explicit SSID
  //    (the config portal's save path). The no-arg WiFi.begin() used everywhere else
  //    (boot loop, manageWiFi retries) reuses the wifi_config_t stored in NVS verbatim.
  WiFi.setScanMethod(WIFI_ALL_CHANNEL_SCAN);
  WiFi.setSortMethod(WIFI_CONNECT_AP_BY_SIGNAL);

  // 2) The stored config itself, which may still carry the core default from whenever
  //    the credentials were last saved: WIFI_FAST_SCAN = first BSSID that answers wins,
  //    i.e. a 1-in-4 lottery. Rewrite it in place; esp_wifi_set_config persists to NVS,
  //    so every later no-arg begin() inherits all-channel + by-signal.
  {
    wifi_config_t conf;
    if (esp_wifi_get_config(WIFI_IF_STA, &conf) == ESP_OK) {
      conf.sta.scan_method     = WIFI_ALL_CHANNEL_SCAN;
      conf.sta.sort_method     = WIFI_CONNECT_AP_BY_SIGNAL;
      conf.sta.threshold.rssi  = -127;  // never skip a candidate for being weak
      esp_wifi_set_config(WIFI_IF_STA, &conf);
    }
  }

  // Ask exactly once, here, while the station interface is definitely up: getWiFiIsSaved()
  // ends in esp_wifi_get_config(WIFI_IF_STA, &conf) with the return value ignored, so with
  // the station disabled - which is precisely the state the AP portal leaves us in - it can
  // hand back uninitialized stack garbage. manageWiFi() reads this latch instead of asking.
  haveSavedWiFi = wm.getWiFiIsSaved();
  DEBUG_PRINTF("WIFI: saved credentials: %s\n", haveSavedWiFi ? "yes" : "no");

  // Load persisted config
  preferences.begin("inverter_config", false);
  strlcpy(IP_char,  preferences.getString("inverter_IP",  "").c_str(), sizeof(IP_char));
  strlcpy(MAC_char, preferences.getString("inverter_MAC", "").c_str(), sizeof(MAC_char));
  inverterIPSet  = preferences.getBool("inverterIPSet",  false) && isValidIP(IP_char);
  inverterMACSet = preferences.getBool("inverterMACSet", false) && MAC_char[0] != '\0';

  pinMode(TRIGGER_PIN, INPUT_PULLUP);

  if (wm_nonblocking) wm.setConfigPortalBlocking(false);

  new (&inverter_input) WiFiManagerParameter(
      "InverterInputID", "Inverter IPv4", IP_char, IP_LEN - 1,
      "placeholder=\"xxx.xxx.xxx.xxx\"");
  new (&inverter_input_2) WiFiManagerParameter(
      "InverterInputID2", "Inverter MAC", MAC_char, MAC_LEN - 1,
      "placeholder=\"xx:xx:xx:xx:xx:xx\" disabled");
  new (&inverter_text) WiFiManagerParameter(
      "<p>The MAC address will be determined automatically after you connect to your local LAN.</p>");

  wm.addParameter(&inverter_input);
  wm.addParameter(&inverter_input_2);
  wm.addParameter(&inverter_text);

  // Only the params callback is wired: setSaveConfigCallback() fires when WiFi
  // credentials are saved, which says nothing about whether an inverter IP was entered.
  wm.setSaveParamsCallback(saveParamCallback);

  std::vector<const char *> menu = {"wifi", "info", "param", "sep", "restart", "exit"};
  wm.setMenu(menu);
  wm.setClass("invert");
  // Portal lifetime is ours, not WiFiManager's: its timeout would shut the AP down
  // and leave the device with neither a portal nor a station link. manageWiFi()
  // cycles AP <-> STA instead, so the device always finds the router again.
  wm.setConfigPortalTimeout(0);
  wm.setCaptivePortalEnable(false);
  wm.setAPClientCheck(true);

  // Classic blocking connect, the old way: begin(), wait, retry - and only after
  // every attempt has failed is WiFiManager allowed to raise the AP portal. Nothing
  // else runs until this window has passed. Re-issuing begin() also retries the
  // whole STA bring-up, which is what fails on the bad boots.
  if (haveSavedWiFi) {
    for (uint8_t attempt = 1;
         attempt <= WIFI_BOOT_ATTEMPTS && WiFi.status() != WL_CONNECTED; attempt++) {
      DEBUG_PRINTF("WIFI: boot connect, attempt %u/%u\n", attempt, WIFI_BOOT_ATTEMPTS);
      char line[21];
      snprintf(line, sizeof(line), "attempt %u of %u", attempt, WIFI_BOOT_ATTEMPTS);
      lcdMessage("WIFI: connecting...", line);

      WiFi.begin();  // no args: the credentials saved in NVS
      uint32_t t0 = millis();
      while (WiFi.status() != WL_CONNECTED && (millis() - t0) < WIFI_BOOT_ATTEMPT_MS) {
        delay(250);
      }
    }
    DEBUG_PRINTF("WIFI: boot connect %s\n",
                 WiFi.status() == WL_CONNECTED ? "succeeded" : "failed - falling back to portal");
  }

  // Already connected by the loop above -> autoConnect() sees WL_CONNECTED and
  // returns true immediately. Only if all attempts failed does it get one try of
  // its own and then raise the AP portal, same as before.
  if (wm.autoConnect(WIFI_APN)) {
    DEBUG_PRINTLN(F("WIFI: connected"));
    lcdMessage("WIFI: connected...");
    wifiOnline = true;
    setupOTA();
    otaReady = true;
    delay(1000);
  } else {
    // autoConnect() has already brought up the soft-AP portal itself. Don't mirror
    // that in a local flag: WiFiManager closes this portal on its own once WiFi is
    // saved (_disableConfigPortal), and would leave the mirror stuck true forever.
    // Do record when it went up - manageWiFi() takes it down again to retry the STA.
    DEBUG_PRINTLN(F("WIFI: not connected - AP config portal open"));
    lcdMessage("WIFI: failed to", "connect, join AP:", WIFI_APN, "192.168.4.1");
    wifiOnline      = false;
    offlineSince    = millis();
    apPortalStarted = millis();
  }

  DEBUG_PRINTF("Saved inverter IP:  %s\n", IP_char[0]  ? IP_char  : "(none)");
  DEBUG_PRINTF("Saved inverter MAC: %s\n", MAC_char[0] ? MAC_char : "(none)");
}

void loop() {
  if (wm_nonblocking) wm.process();

  // Owns every WiFi state transition: reconnects a dropped link, raises the AP portal
  // when the outage is long, and tears that portal back down so the STA can retry.
  manageWiFi();

  if (otaReady) ArduinoOTA.handle();

  checkButton();

  // Keep the LAN web portal up for as long as we have WiFi: it is the only way to
  // change the inverter IP later, and it costs nothing but the web server.
  // Guarded by portalActive(): v1 called startConfigPortal() on every loop
  // iteration, restarting the portal continuously.
  if (WiFi.status() == WL_CONNECTED && !portalActive()) {
    openPortal();
  }

  // Everything below needs the network. Without this guard a WiFi outage looked
  // exactly like a dead inverter: the poll kept firing, every GET failed, and six
  // failures rebooted the device straight into the AP portal.
  if (WiFi.status() != WL_CONNECTED) return;

  // No inverter IP: nothing below can run until one is entered in the web portal, so
  // keep that request on the LCD. openPortal() used to paint it once, when the portal
  // started, and the next message - a WiFi reconnect - buried it for good.
  if (!inverterIPSet) {
    if (onScreen != LcdScreen::IpPrompt) showIPPrompt();
    return;
  }

  if (!inverterMACSet) {
    resolveMAC();
    return;
  }

  // Handshake: confirm the box at IP_char is still our inverter, and that it speaks
  // Solar API v1. Retried with backoff until it succeeds - see runInverterHandshake().
  if (!initSuccess) {
    runInverterHandshake();
    return;
  }

  // The inverter stopped answering. Rebooting cannot wake it, and used to re-run the
  // handshake at exactly the moment it would fail and delete the stored IP. Drop back
  // to the handshake instead, which retries with backoff and owns the LCD meanwhile.
  if (connectErrors > MAX_CONNECT_ERRORS) {
    DEBUG_PRINTLN(F("Inverter stopped responding, back to handshake retries"));
    initSuccess          = false;
    connectErrors        = 0;
    errorTimeout         = 0;
    inverterProblem      = "stopped responding";
    lastHandshakeAttempt = millis();  // first retry after HANDSHAKE_RETRY_MIN_MS
    handshakeBackoff     = HANDSHAKE_RETRY_MIN_MS;
    showInverterOffline();
    return;
  }
  if (errorTimeout != 0 && (millis() - errorTimeout) > ERROR_RESET_MS) {
    connectErrors = 0;
    errorTimeout  = 0;
  }

  // Main screen
  if (initSuccess && (millis() - pollTimeout) > POLL_INTERVAL_MS) {
    pollTimeout = millis();
    PowerData   prm = getInverterData();
    GridVoltage gv  = getGridVoltage();
    drawPowerScreen(prm, gv);
  }
}

/* ---- Display ---- */

void lcdMessage(const char *l0, const char *l1, const char *l2, const char *l3) {
  onScreen = LcdScreen::Other;
  lcd.clear();
  const char *lines[4] = {l0, l1, l2, l3};
  for (int i = 0; i < 4; i++) {
    if (lines[i] == nullptr) continue;
    lcd.setCursor(0, i);
    lcd.print(lines[i]);
  }
}

// Both paint through lcdMessage() - which marks the LCD Other - and then claim it.
void showIPPrompt() {
  lcdMessage("Set inverter IP at", WiFi.localIP().toString().c_str());
  onScreen = LcdScreen::IpPrompt;
}

void showInverterOffline() {
  lcdMessage("Inverter unavailable", IP_char, inverterProblem, "retrying...");
  onScreen = LcdScreen::InverterOffline;
}

// Formats watts as "1234W" or "12.3kW" into buf.
static void formatPower(int watts, char *buf, size_t len) {
  int w = abs(watts);
  if (w < 1000) {
    snprintf(buf, len, "%dW", w);
  } else {
    snprintf(buf, len, "%.1fkW", w / 1000.0f);
  }
}

void drawPowerScreen(const PowerData &prm, const GridVoltage &gv) {
  onScreen = LcdScreen::Other;
  lcd.clear();

  // PV production (row 0)
  char pv[12];
  formatPower(prm.pvProduction, pv, sizeof(pv));
  lcd.setCursor(2, 0);
  lcd.write(0b10110010);
  lcd.write(0b10110010);
  lcd.print(" ");
  lcd.print(pv);

  // House (rows 1-2, cols 0-1)
  lcd.setCursor(0, 2); lcd.write(byte(0));
  lcd.setCursor(1, 2); lcd.write(byte(1));
  lcd.setCursor(0, 1); lcd.write(byte(2));
  lcd.setCursor(1, 1); lcd.write(byte(3));

  // Pole (rows 0-2, cols 18-19). CGRAM slots 4-7 are only needed here.
  lcd.createChar(4, PoleTLeft);
  lcd.createChar(5, PoleTRight);
  lcd.createChar(6, PoleMLeft);
  lcd.createChar(7, PoleMRight);

  lcd.setCursor(18, 0); lcd.write(byte(4));
  lcd.setCursor(18, 1); lcd.write(byte(6));
  lcd.setCursor(18, 2); lcd.print(F("|"));
  lcd.setCursor(19, 0); lcd.write(byte(5));
  lcd.setCursor(19, 1); lcd.write(byte(7));
  lcd.setCursor(19, 2); lcd.print(F("|"));

  // Grid flow (row 2). v1 built this with strcat() into char[7]/char[12] buffers
  // and overran both - the export branch wrote ~15 bytes into a 7-byte stack
  // buffer on every refresh. snprintf into one correctly-sized buffer instead.
  char power[12];
  formatPower(prm.gridConsumption, power, sizeof(power));

  char gridLine[20];
  if (prm.gridConsumption > 0) {
    // Importing: grid -> house
    snprintf(gridLine, sizeof(gridLine), "<  <  < %s", power);
  } else {
    // Exporting: house -> grid
    snprintf(gridLine, sizeof(gridLine), "%s >  >  >", power);
  }
  lcd.setCursor(3, 2);
  lcd.print(gridLine);

  // Status (row 3)
  char status[20];
  snprintf(status, sizeof(status), "%d%%gV %dE %ddRSSI",
           gv.devPercent, connectErrors, (int)WiFi.RSSI());
  lcd.setCursor(2, 3);
  lcd.print(status);
}

/* ---- Fronius Solar API ---- */

// Builds "http://<ip><endpoint>". Returns false if it would not fit.
bool buildURL(char *out, size_t outLen, const char *endpoint) {
  int n = snprintf(out, outLen, "%s%s%s", HTTPSTRING, IP_char, endpoint);
  if (n < 0 || (size_t)n >= outLen) {
    DEBUG_PRINTF("buildURL: URL too long for %u-byte buffer\n", (unsigned)outLen);
    return false;
  }
  return true;
}

String httpGETRequest(const char *serverPath) {
  HTTPClient http;
  DEBUG_PRINTF("Requesting URL: %s\n", serverPath);

  http.begin(serverPath);
  int httpResponseCode = http.GET();
  String payload = "{}";

  if (httpResponseCode > 0) {
    DEBUG_PRINTF("HTTP Response code: %d\n", httpResponseCode);
    payload = http.getString();
  } else {
    DEBUG_PRINTF("HTTP error code: %d\n", httpResponseCode);
    onScreen = LcdScreen::Other;
    lcd.clear();
    lcd.setCursor(0, 0);
    lcd.print(F("HTTP Error: "));
    lcd.print(httpResponseCode);
    lcd.setCursor(0, 1);
    lcd.print(F("Inverter unavailable"));
  }

  http.end();
  return payload;
}
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

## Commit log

2026-07-12 Initial commit: Fronius Solar Display v2 (Waveshare ESP32-S3-ETH)
    Port of Fronius_Solar_Display from the ESP32 WROOM DA / DevKit V1, plus
    fixes to the WiFi config-portal state machine:
    - Portal state is now read back from WiFiManager via portalActive() instead
    of being mirrored in a local flag. WiFiManager shuts its own AP portal down
    once WiFi credentials are saved (_disableConfigPortal), with no callback, so
    the mirrored flag latched true forever and loop() could never open the web
    portal or repaint the LCD.
    - closePortal() no longer drops the AP portal while WiFi is unconnected.
    Saving the inverter IP before configuring WiFi used to tear the portal down
    mid-setup, leaving the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
    [Autoscroll.ino, Blink.ino, Cursor.ino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]
2026-07-12 Keep the LAN web portal up whenever WiFi is connected
    The web portal was gated on !inverterIPSet, so once an inverter IP had been
    saved there was nothing listening on port 80 and the config page was only
    reachable by tapping BOOT. It is the only way to change the inverter IP later,
    so serve it for as long as we have WiFi; it costs a web server and nothing else.
    openPortal() now only claims the LCD while the inverter IP is still missing -
    otherwise the power screen owns the display.
    With the portal permanently up, closePortal() had nothing left to do, so it is
    gone along with its call in saveParamCallback(). That call was the bug that
    could tear the soft-AP portal down before WiFi credentia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
    [main.cpp]
2026-07-12 Add Waveshare ESP32-S3-ETH board reference to docs/
    Moved out of include/, which is PlatformIO's header directory. This is the
    board manual; its antenna-switch page documents the 0R resistor that selects
    between the onboard ceramic antenna and the u.FL/IPEX connector.
2026-07-13 Fix gV stuck at 0%: select the grid meter by location, not by key
    getGridVoltage() read Body.Data.0 from GetMeterRealtimeData, but the Datamanager
    assigns the meter device IDs: this system reports its grid meter as "2" and the
    Carport meter as "3", with no "0" at all. The lookup never matched, so every poll
    took the "Meter data not available" branch and returned the zero-initialised
    struct - a permanent 0%gV on the display.
    Walk Body.Data and select by Meter_Location_Current instead (Solar API v1 spec
    4.8.5): 0 = grid interconnection point, falling back only to 1 = load-path
    primary. Secondary meters (3 = external generator, 256-511 = subloads) are never
    picked - they report the voltage at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
    [main.cpp]
2026-07-13 Document the X: share build/flash gotchas
    Two environment traps cost time this session and neither is discoverable from the
    code: SCons cannot write .sconsign over SMB (the build fails *after* a successful
    compile, so it reads as a code error), and the VPN that mounts X: is the same VPN
    that hides the display from OTA - so the source tree is unreachable exactly when
    you need to flash. Record the PLATFORMIO_BUILD_DIR workaround and the espota.py
    route that needs no project directory.
2026-07-13 Reconnect to WiFi instead of stranding in the config portal
    The display had no WiFi reconnect logic at all -- and neither did v1. Both
    leaned on the Arduino core's silent auto-reconnect, which dies the moment
    WiFiManager raises the soft-AP: startConfigPortal() calls WiFi_enableSTA(false),
    so a device parked in that portal has no station left to notice the router come
    back. WiFiManager itself only reconnects under #ifdef esp32autoreconnect, which
    is not defined.
    A router outage was therefore a one-way trip: the 5s poll kept firing with WiFi
    down, every GET failed, six failures rebooted the box, autoConnect() failed while
    the router was still down, up went the AP portal -- stranded until a po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
    [main.cpp]
2026-07-13 Document the antenna switch: -85 dBm was a 0R resistor, not the site
    The display read -80..-90 dBm from an AP 8 m away in the same room with clear
    line of sight, where free-space loss says it should read in the -40s. A 30-45 dB
    deficit is a broken RF path, not a weak signal -- but it presented as flaky WiFi
    and sent us tuning the radio and blaming the router.
    The board defaults to its on-board PCB antenna, and the IPEX connector is dead
    until a 0R resistor is moved: vertical = internal (factory default), horizontal =
    external. Both traps are recorded, including the nasty one -- soldering an antenna
    straight onto the bridge pads improves RSSI (any conductor on the feed radiates)
    while leavin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
2026-09-13 Connect over WiFi before WiFiManager can raise the portal
    wm.autoConnect() makes exactly one attempt with no timeout and no
    retries (_connectTimeout=0, _connectRetries=1). On the Arduino 3.x core
    a transient STA bring-up hiccup fails that attempt in ~0 ms - silently,
    only log_e() - and the device lands in the AP portal without ever having
    tried the router. The tell was the missing 3-5 s connect lag on reset.
    setup() now does the classic thing first: if credentials are saved, a
    blocking begin()-and-wait loop, 2 x 10 s, attempt counter on the LCD.
    Re-issuing begin() re-runs the whole STA bring-up, which is the part
    that fails. autoConnect() then either sees WL_CONNECTED and returns
    immediatel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
    [main.cpp]
2026-09-13 Port to the ESP32-WROOM-32 DevKit after the S3 board died
    The Waveshare ESP32-S3-ETH failed and is replaced by a uPesy ESP-WROOM-32
    DevKit - back to v1's board family. Application logic is untouched; this
    is pinout, build config and the docs that go with them.
    Pinout returns to v1's proven wiring with one wire moved:
    RS=13 EN=33 D4=14 D5=27 D6=26 D7=25
    v1 had EN on 12. GPIO12 is MTDI and is sampled at reset to pick the flash
    core voltage - held high it selects 1.8 V and the module will not boot or
    flash. v1 got away with it because the HD44780's E input is high-impedance,
    but the pad sits inside the run we use, between D4 and GND, so a miscount
    of one lands on it. 33 has no boot-ti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
    [main.cpp]
2026-09-13 Add README, licence and case files for the public repo
    v2 was started as a fresh tree and never carried these across, so the
    repository had no landing page and, more importantly, no licence.
    LICENSE.md (CC BY-NC 4.0), the display photo and the printable 20x4 cap
    come over from v1 unchanged.
    The README is new rather than v1's: the pinout, the power requirement and
    the flashing procedure have all changed, and v1's README documents a board
    this code no longer runs on.
    v1's Fritzing sketch is deliberately NOT carried over. It shows EN on
    GPIO12, which was v1's wiring and is wrong for v2 - a diagram that
    contradicts the code is worse than no diagram. It remains available on the
    v1 branch.
    Co-A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
    [20x4_cap_all.3mf]
2026-09-14 Keep the inverter address when the inverter goes quiet
    The display was found stuck on "WIFI: connected / 10.0.0.22" and needed
    the inverter IP re-entered. It had not hung. The firmware had deleted
    its own configuration:
    1. The inverter stopped answering - Fronius Datamanagers switch off at
    night unless Night Mode is on.
    2. More than five failed polls -> ESP.restart().
    3. The boot handshake ran while the inverter was still silent, found it
    neither by IP nor by MAC sweep, and wrote inverterIPSet = false.
    4. loop() then had no IP and did nothing. Its only prompt, "Set inverter
    IP", was painted once when the web portal opened; the next WiFi
    reconnect painted over it and nothing ever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
    [main.cpp]
